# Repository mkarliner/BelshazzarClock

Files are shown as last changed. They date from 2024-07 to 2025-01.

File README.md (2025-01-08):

# Belshazzar Luminous Night Clock

Here are the files for the PCB, micropython code and STL files for Belshazzar's Clock.
Refer to the KiCad files for the PCB details and BOM for details of compononents, but they
are basically WS2811 SOT8 led drivers, 0805 SMD UV leds and a a small number of resistors and
caps, also 0805 SMD.

There are four 3D printed parts, which are small enough to print on most printers.

You will additionally need -

- Stepper Motor 28BYJ-48 with ULN2003 Driver Board
- 200mm of 100mm ID plastic ducting pipe.
- White paint or paper to cover the pipe
- Glow in the dark paint
- ESP32C3 Super Mini dev board

  I've left a space for a 74AHCT125 level converter to boost the 3.3V logic of the ESP32 to 5V for the WS2811, but on my board at least, it works fine without, you can just jumper over the in and out pins on the level converter.

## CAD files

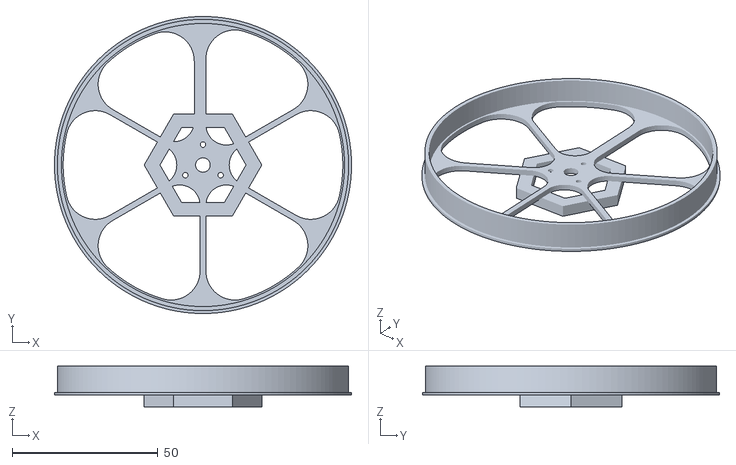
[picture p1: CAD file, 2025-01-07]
hardware/Clock Drum Motor End.stl
102.0 x 102.0 x 14.0

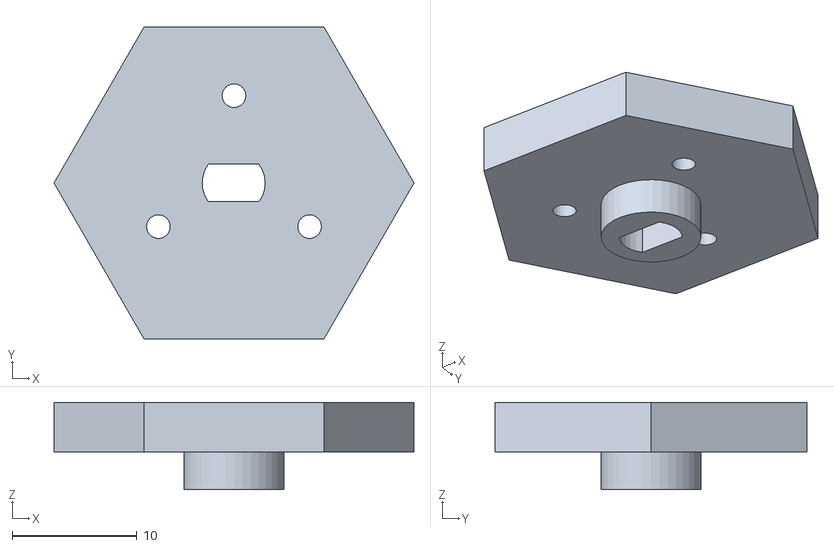
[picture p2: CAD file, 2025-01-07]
hardware/Clock Drum Motor Plate.stl
28.9 x 25.0 x 7.00

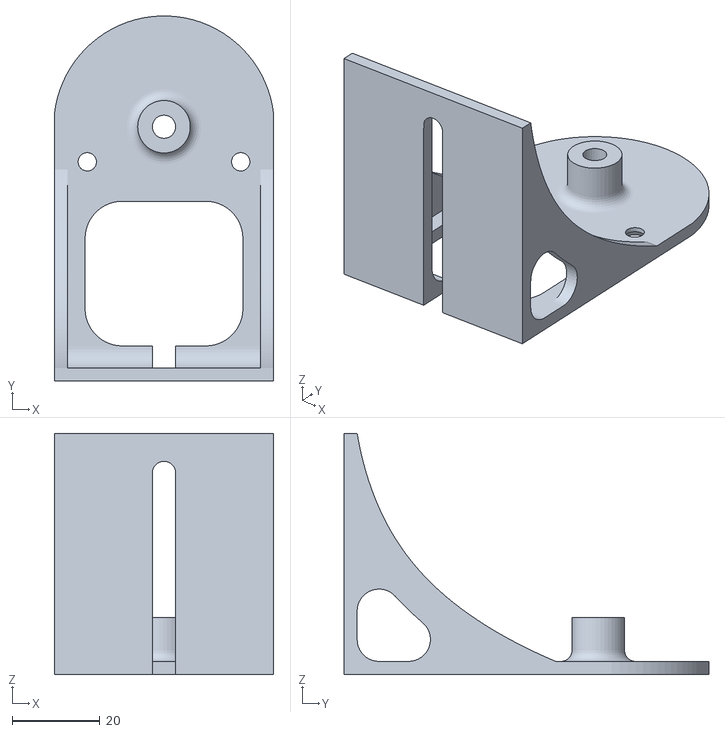
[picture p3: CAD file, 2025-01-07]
hardware/Base Bracket B.stl
50.0 x 83.3 x 55.0

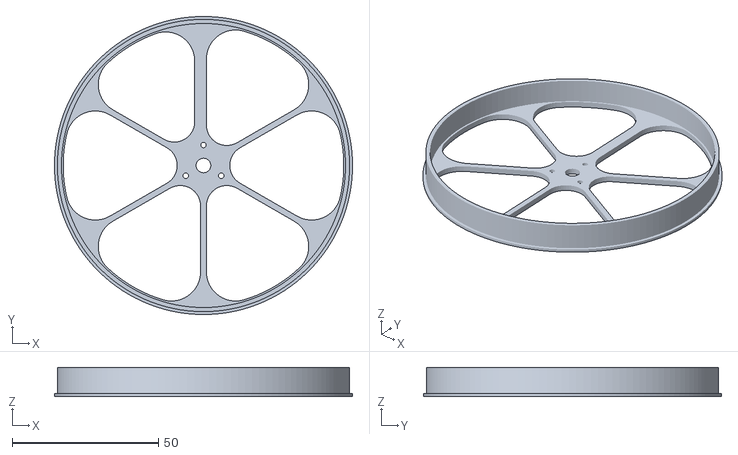
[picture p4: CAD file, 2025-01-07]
hardware/Clock Drum Idler.stl
102.0 x 102.0 x 10.0

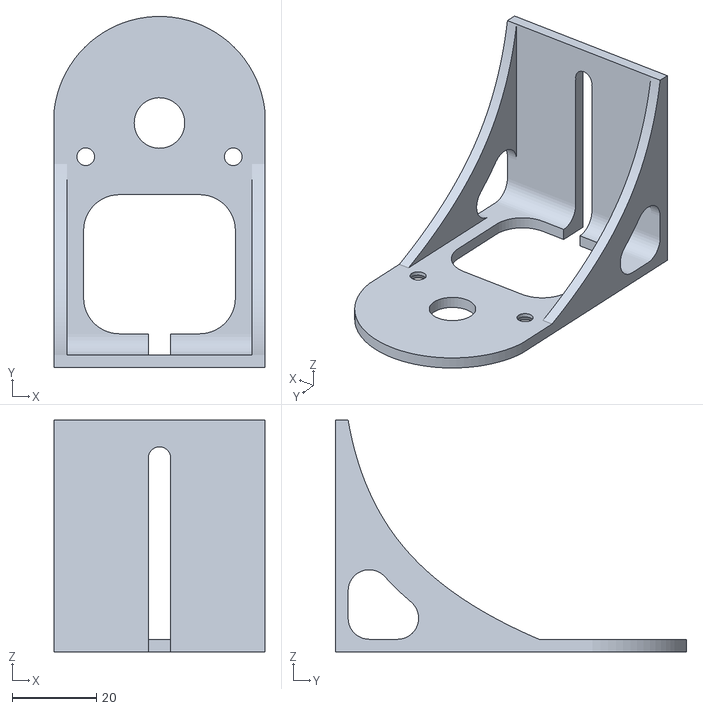
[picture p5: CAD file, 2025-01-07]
hardware/Base Bracket A.stl
50.0 x 83.3 x 55.0

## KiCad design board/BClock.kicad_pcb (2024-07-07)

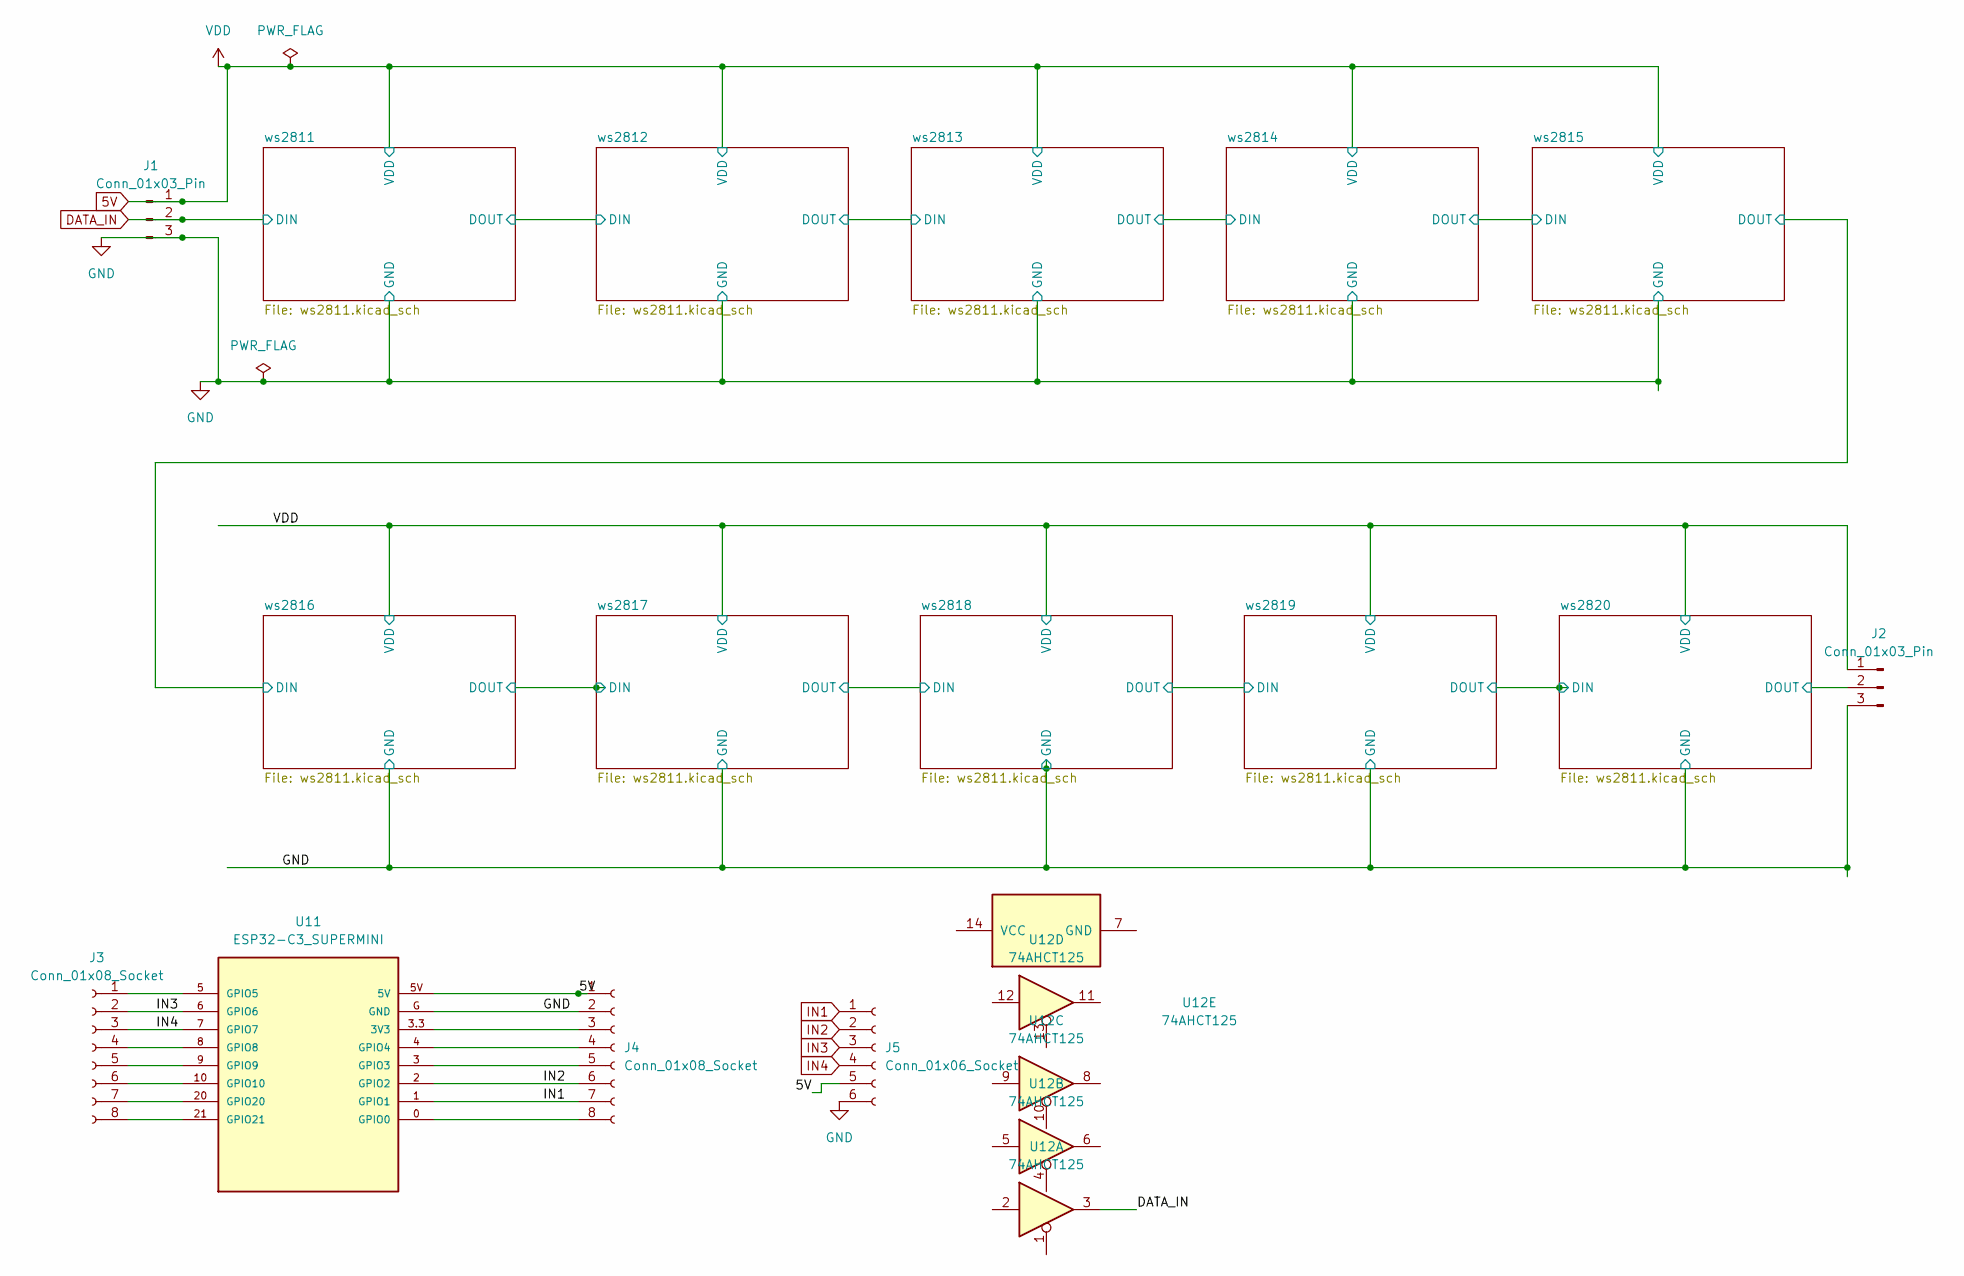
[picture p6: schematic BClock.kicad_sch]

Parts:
J1, J2: Conn_01x03_Pin; PinHeader_1x03_P2.54mm_Vertical
J3, J4: Conn_01x08_Socket; PinHeader_1x08_P2.54mm_Vertical
J5: Conn_01x06_Socket; PinHeader_1x06_P2.54mm_Vertical
U11: ESP32-C3_SUPERMINI; MODULE_ESP32-C3_SUPERMINI
U12: 74AHCT125; DIP-14_W10.16mm

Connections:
5V: J1.1, J2.1, J4.1, J5.5, U11.5V; also elsewhere on the board
/ws2820/DOUT: J2.2; also elsewhere on the board
DATA_IN: J1.2, U12.3; also elsewhere on the board
GND: J1.3, J2.3, J4.2, J5.6, U11.G (GND); also elsewhere on the board
IN1: J4.7, J5.1, U11.1 (GPIO1)
IN2: J4.6, J5.2, U11.2 (GPIO2)
IN3: J3.2, J5.3, U11.6 (GPIO6)
IN4: J3.3, J5.4, U11.7 (GPIO7)
unnamed: J3.1, U11.5 (GPIO5)
unnamed: J3.4, U11.8 (GPIO8)
unnamed: J3.5, U11.9 (GPIO9)
unnamed: J3.6, U11.10 (GPIO10)
unnamed: J3.7, U11.20 (GPIO20)
unnamed: J3.8, U11.21 (GPIO21)
unnamed: J4.3, U11.3.3 (3V3)
unnamed: J4.4, U11.4 (GPIO4)
unnamed: J4.5, U11.3 (GPIO3)
unnamed: J4.8, U11.0 (GPIO0)

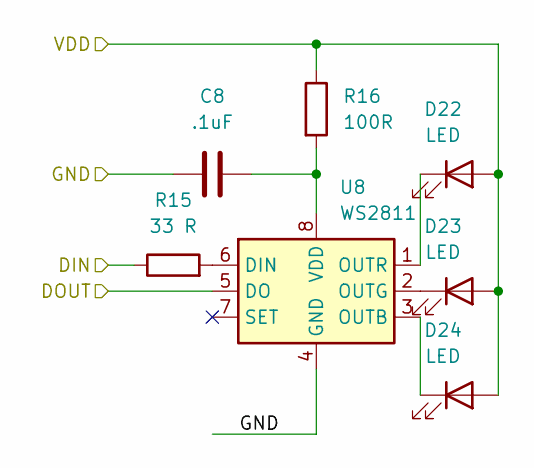
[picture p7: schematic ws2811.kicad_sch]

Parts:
C8: .1uF; C_0805_2012Metric
D22, D23, D24: LED; LED_0805_2012Metric
R15: 33 R; R_0805_2012Metric
R16: 100R; R_0805_2012Metric
U8: WS2811; SOP-8_3.9x4.9mm_P1.27mm

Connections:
5V: D22.2 (A), D23.2 (A), D24.2 (A), R16.1; also elsewhere on the board
/ws2817/DOUT: R15.1; also elsewhere on the board
/ws2818/DOUT: U8.5 (DO); also elsewhere on the board
GND: C8.1, U8.4 (GND); also elsewhere on the board
unnamed: D22.1 (K), U8.1 (OUTR)
unnamed: D23.1 (K), U8.2 (OUTG)
unnamed: D24.1 (K), U8.3 (OUTB)
unnamed: R15.2, U8.6 (DIN)
unnamed: C8.2, R16.2, U8.8 (VDD)

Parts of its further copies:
C1, C2, C3, C4, C5, C6, C7, C9, C10: .1uF; C_0805_2012Metric
D1, D2, D3, D4, D5, D6, D7, D8, D9, D10, D11, D12, D13, D14, D15, D16, D17, D18, D19, D20, D21, D25, D26, D27, D28, D29, D30: LED; LED_0805_2012Metric
R1, R3, R5, R7, R9, R11, R13, R17, R19: 33 R; R_0805_2012Metric
R2, R4, R6, R8, R10, R12, R14, R18, R20: 100R; R_0805_2012Metric
U1, U2, U3, U4, U5, U6, U7, U9, U10: WS2811; SOP-8_3.9x4.9mm_P1.27mm

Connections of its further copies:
5V: D1.2 (A), D2.2 (A), D3.2 (A), D4.2 (A), D5.2 (A), D6.2 (A), D7.2 (A), D8.2 (A), D9.2 (A), D10.2 (A), D11.2 (A), D12.2 (A), D13.2 (A), D14.2 (A), D15.2 (A), D16.2 (A), D17.2 (A), D18.2 (A), D19.2 (A), D20.2 (A), D21.2 (A), D25.2 (A), D26.2 (A), D27.2 (A), D28.2 (A), D29.2 (A), D30.2 (A), R2.1, R4.1, R6.1, R8.1, R10.1, R12.1, R14.1, R18.1, R20.1; also elsewhere on the board
/ws2811/DOUT: R3.1, U1.5 (DO)
/ws2812/DOUT: R5.1, U2.5 (DO)
/ws2813/DOUT: R7.1, U3.5 (DO)
/ws2814/DOUT: R9.1, U4.5 (DO)
/ws2815/DOUT: R11.1, U5.5 (DO)
/ws2816/DOUT: R13.1, U6.5 (DO)
/ws2817/DOUT: U7.5 (DO); also elsewhere on the board
/ws2818/DOUT: R17.1; also elsewhere on the board
/ws2819/DOUT: R19.1, U9.5 (DO)
/ws2820/DOUT: U10.5 (DO); also elsewhere on the board
DATA_IN: R1.1; also elsewhere on the board
GND: C1.1, C2.1, C3.1, C4.1, C5.1, C6.1, C7.1, C9.1, C10.1, U1.4 (GND), U2.4 (GND), U3.4 (GND), U4.4 (GND), U5.4 (GND), U6.4 (GND), U7.4 (GND), U9.4 (GND), U10.4 (GND); also elsewhere on the board
unnamed: D1.1 (K), U1.1 (OUTR)
unnamed: D2.1 (K), U1.2 (OUTG)
unnamed: D3.1 (K), U1.3 (OUTB)
unnamed: D4.1 (K), U2.1 (OUTR)
unnamed: D5.1 (K), U2.2 (OUTG)
unnamed: D6.1 (K), U2.3 (OUTB)
unnamed: D7.1 (K), U3.1 (OUTR)
unnamed: D8.1 (K), U3.2 (OUTG)
unnamed: D9.1 (K), U3.3 (OUTB)
unnamed: D10.1 (K), U4.1 (OUTR)
unnamed: D11.1 (K), U4.2 (OUTG)
unnamed: D12.1 (K), U4.3 (OUTB)
unnamed: D13.1 (K), U5.1 (OUTR)
unnamed: D14.1 (K), U5.2 (OUTG)
unnamed: D15.1 (K), U5.3 (OUTB)
unnamed: D16.1 (K), U6.1 (OUTR)
unnamed: D17.1 (K), U6.2 (OUTG)
unnamed: D18.1 (K), U6.3 (OUTB)
unnamed: D19.1 (K), U7.1 (OUTR)
unnamed: D20.1 (K), U7.2 (OUTG)
unnamed: D21.1 (K), U7.3 (OUTB)
unnamed: D25.1 (K), U9.1 (OUTR)
unnamed: D26.1 (K), U9.2 (OUTG)
unnamed: D27.1 (K), U9.3 (OUTB)
unnamed: D28.1 (K), U10.1 (OUTR)
unnamed: D29.1 (K), U10.2 (OUTG)
unnamed: D30.1 (K), U10.3 (OUTB)
unnamed: R1.2, U1.6 (DIN)
unnamed: C1.2, R2.2, U1.8 (VDD)
unnamed: R3.2, U2.6 (DIN)
unnamed: C2.2, R4.2, U2.8 (VDD)
unnamed: R5.2, U3.6 (DIN)
unnamed: C3.2, R6.2, U3.8 (VDD)
unnamed: R7.2, U4.6 (DIN)
unnamed: C4.2, R8.2, U4.8 (VDD)
unnamed: R9.2, U5.6 (DIN)
unnamed: C5.2, R10.2, U5.8 (VDD)
unnamed: R11.2, U6.6 (DIN)
unnamed: C6.2, R12.2, U6.8 (VDD)
unnamed: R13.2, U7.6 (DIN)
unnamed: C7.2, R14.2, U7.8 (VDD)
unnamed: R17.2, U9.6 (DIN)
unnamed: C9.2, R18.2, U9.8 (VDD)
unnamed: R19.2, U10.6 (DIN)
unnamed: C10.2, R20.2, U10.8 (VDD)

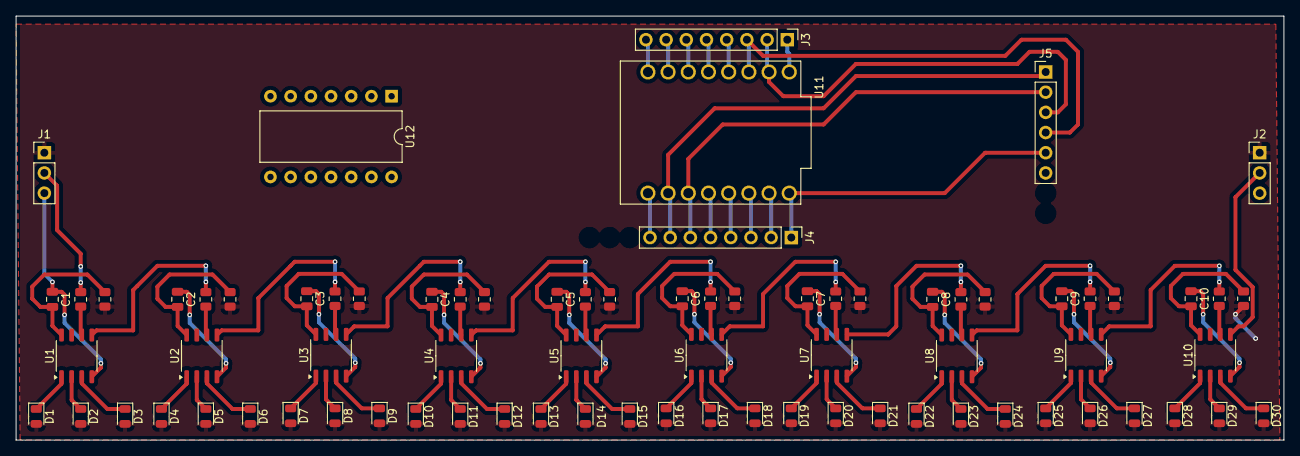
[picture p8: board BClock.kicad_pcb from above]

Board: 2 copper layers, 159.5 x 53.3 mm, 77 parts (0 on the bottom side), 77 nets.

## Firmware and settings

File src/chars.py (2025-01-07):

# Raster images of the numbers 1 to 10 in 6x10 arrays

chars = {
    '0': [
        " #### ",
        "#    #",
        "#    #",
        "#    #",
        "#    #",
        "#    #",
        "#    #",
        "#    #",
        "#    #",
        " #### ",
    ],
    '1': [
        "  ##  ",
        " # #  ",
        "   #  ",
        "   #  ",
        "   #  ",
        "   #  ",
        "   #  ",
        "   #  ",
        "   #  ",
        " #### ",
    ],
    '2': [
        " #### ",
        "#    #",
        "     #",
        "     #",
        "    # ",
        "   #  ",
        "  #   ",
        " #    ",
        " #    ",
        "######",
    ],
    '3': [
        " #### ",
        "#    #",
        "     #",
        "     #",
        " #### ",
        "     #",
        "     #",
        "     #",
        "#    #",
        " #### ",
    ],
    '4': [
        "   ## ",
        "  # # ",
        " #  # ",
        "#   # ",
        "#   # ",
        "######",
        "    # ",
        "    # ",
        "    # ",
        "    # ",
    ],
    '5': [
        "######",
        "#     ",
        "#     ",
        "##### ",
        "     #",
        "     #",
        "     #",
        "     #",
        "#    #",
        " #### ",
    ],
    '6': [
        " #### ",
        "#    #",
        "#     ",
        "#     ",
        "##### ",
        "#    #",
        "#    #",
        "#    #",
        "#    #",
        " #### ",
    ],
    '7': [
        "######",
        "     #",
        "     #",
        "     #",
        "    # ",
        "   #  ",
        "  #   ",
        "  #   ",
        "  #   ",
        "  #   ",
    ],
    '8': [
        " #### ",
        "#    #",
        "#    #",
        "#    #",
        " #### ",
        "#    #",
        "#    #",
        "#    #",
        "#    #",
        " #### ",
    ],
    '9': [
        " #### ",
        "#    #",
        "#    #",
        "#    #",
        " #####",
        "     #",
        "     #",
        "     #",
        "#    #",
        " #### ",
    ]
}

if __name__ == "__main__":
    for number, raster in numbers.items():
        print(f"Number {number}:")
        for line in raster:
            print(line)
        print()

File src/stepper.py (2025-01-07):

# Rui Santos & Sara Santos - Random Nerd Tutorials
# Complete project details at https://RandomNerdTutorials.com/raspberry-pi-pico-stepper-motor-micropython/
# Forked from: https://github.com/larsks/micropython-stepper-motor/blob/master/motor.py

import machine
import time

class Motor:
    stepms = 10

    # Do be defined by subclasses
    maxpos = 0
    states = []

    def __init__(self, p1, p2, p3, p4, stepms=None):
        self.pins = [p1, p2, p3, p4]

        if stepms is not None:
            self.stepms = stepms

        self._state = 0
        self._pos = 0

    def __repr__(self):
        return '<{} @ {}>'.format(
            self.__class__.__name__,
            self.pos,
        )

    @property
    def pos(self):
        return self._pos

    @classmethod
    def frompins(cls, *pins, **kwargs):
        return cls(*[machine.Pin(pin, machine.Pin.OUT) for pin in pins],
                   **kwargs)

    def reset(self):
        self._pos = 0

    def _step(self, dir):
        state = self.states[self._state]

        for i, val in enumerate(state):
            self.pins[i].value(val)

        self._state = (self._state + dir) % len(self.states)
        self._pos = (self._pos + dir) % self.maxpos

    def step(self, steps):
        dir = 1 if steps >= 0 else -1
        steps = abs(steps)

        for _ in range(steps):
            t_start = time.ticks_ms()

            self._step(dir)

            t_end = time.ticks_ms()
            t_delta = time.ticks_diff(t_end, t_start)
            time.sleep_ms(self.stepms - t_delta)

    def step_until(self, target, dir=None):
        if target < 0 or target > self.maxpos:
            raise ValueError(target)

        if dir is None:
            dir = 1 if target > self._pos else -1
            if abs(target - self._pos) > self.maxpos/2:
                dir = -dir

        while True:
            if self._pos == target:
                break
            self.step(dir)

    def step_until_angle(self, angle, dir=None):
        if angle < 0 or angle > 360:
            raise ValueError(angle)

        target = int(angle / 360 * self.maxpos)
        self.step_until(target, dir=dir)
        
    def step_degrees(self, degrees):
        if degrees < 0 or degrees > 360:
            raise ValueError("Degrees should be between 0 and 360")

        steps_to_take = int(degrees / 360 * self.maxpos)

#         self.zero()  # Ignore the current position, start from zero
        self.step(steps_to_take)

class FullStepMotor(Motor):
    stepms = 5
    maxpos = 2048
    states = [
        [1, 1, 0, 0],
        [0, 1, 1, 0],
        [0, 0, 1, 1],
        [1, 0, 0, 1],
    ]


class HalfStepMotor(Motor):
    stepms = 3
    maxpos = 4096
    states = [
        [1, 0, 0, 0],
        [1, 1, 0, 0],
        [0, 1, 0, 0],
        [0, 1, 1, 0],
        [0, 0, 1, 0],
        [0, 0, 1, 1],
        [0, 0, 0, 1],
        [1, 0, 0, 1],
    ]

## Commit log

2024-06-20 NEW: First commit
    [BClock-B_Cu.gbl, BClock-B_Mask.gbs, BClock-B_Paste.gbp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]
2024-07-07 NEW: Added ESP32C3 and level shifter
    [BClock.kicad_pcb, BClock.kicad_sch, ws2811.kicad_sch]
2025-01-07 CHANGE: Unified repo with electronics and source code
    [BClock-B_Cu.gbl, BClock-B_Mask.gbs, BClock-B_Paste.gbp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]
2025-01-07 ADD: STL files for 3D printing
    [Base Bracket A.stl, Base Bracket B.stl, Clock Drum Idler.stl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]
